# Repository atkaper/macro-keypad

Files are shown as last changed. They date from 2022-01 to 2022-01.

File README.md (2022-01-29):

# Macro Keypad

The Macro Keypad is an 8 key USB keyboard, with programmable keys, and a led in each key.
See blog post: https://www.kaper.com/electronics/macro-keypad/ for schematics, more information, and on
how to build this.

## Some images of the end result

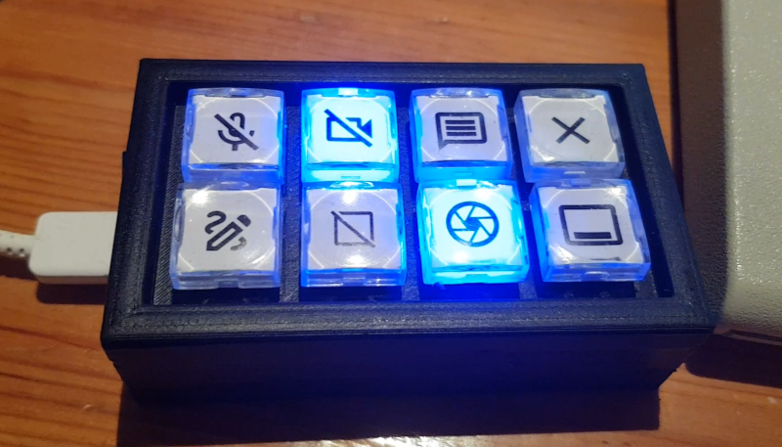
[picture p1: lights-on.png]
Lights On


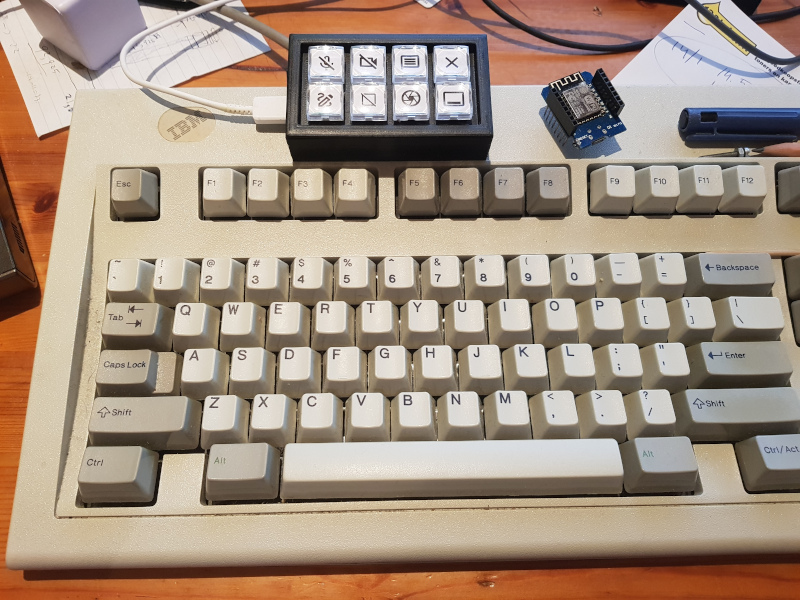
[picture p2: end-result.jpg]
End Result


## Used components

The next (2) titles are taken from the Aliexpress site, where I ordered the parts:

- Honyone TS26 Series Square With LED Momentary SPST PCB Mini Push Button Tact Switch -->  [12x 0.81 euro, when I bought them].
- PRO MICRO/MINI/TYPE-C USB 5V 16MHz Board Module For Arduino/Leonardo ATMEGA32U4-AU/MU Controller Pro-Micro Replace Pro Mini 1PCS -->  [1x 5.62 euro, when I bought it - I took the USB-C one].
- 8x 100 Ohm resistor (taken from a previously ordered set of many resistor values).
- Some spare through-hole protoboard (experiment printed circuit board).

## Files/Folders in this Git Repository

Folders:

- ```3d-files``` ; contains the blender and STL files to print the case.
- ```MacroKeyPad``` ; contains the Arduino code to run on the microcontroller.
- ```Linux-Tools``` ; contains Linux scripts I use for executing macro's and talking to the keypad lights.

Linux-Tools Files:

- ```key-macros.sh``` ; a shell script which can execute some functions I needed. These include talking to MS-Teams
  chat/video, drawing on screen, region-screenshot, and starting a terminal/shell.
- ```send-macropad-command.py``` ; python script to change led states, and change key functions/mappings.

## Compile code / program the controller

The ```MacroKeyPad.ino``` in the ```MacroKeyPad``` folder can be opened in the Arduino IDE (see https://www.arduino.cc/).
To compile the code ("sketch"), you need to add support for the Arduino Leonardo ATMEGA 32U4 Pro micro.
Use this URL as board manager setting (Files / Preferences / Additional Boards Manager URLs):
https://raw.githubusercontent.com/sparkfun/Arduino_Boards/master/IDE_Board_Manager/package_sparkfun_index.json
Via: Tools / Board / Boards Manager you can add missing boards.

In Tools menu: Choose board "SparkFun Pro Micro", CPU 16 MHZ, 5V. And the proper device to send it to.
For me that was: /dev/ttyACM0. And then hit the "upload" button.
If it does not understand some of the used includes, you might need to add some libraries using the:
Sketch / Include Library / Manage Libraries menu item.

Unfortunately, my Arduino IDE already has all stuff I need, so I do not know what you will need to add ;-)
Perhaps one day I'll try a fresh installation to write down the exact steps. For now, just use an internet
search if you get stuck.

After you did program the controller, and completed building it, you are ready to test it.
The ```send-macropad-command.py``` tool can be used to change behaviour, and change led states.
And for the rest you will need to either put the proper key you need in the keypad definition, or
use your operating systems keyboard mapping possibilities or external tools to add special actions on each
key-press.

For me this was simple. I have mapped the F13..F22 keys to the keypad, and in Linux Mint, I can simply
open up the Keyboard GUI program to assign Application Shortcuts to those keys. As shortcuts I used the
shell script ```key-macros.sh``` for the different functions. But some of these can also be done directly in the
Keyboard GUI settings.

Note: the two ```Linux-Tools``` script files should be places in a ```bin``` folder in your path. I used my
bin folder in my user's home directory for that, and added it to the PATH setting.

For more information, see the blog-post as mentioned at the top of this page.

Thijs Kaper, January 29, 2022.

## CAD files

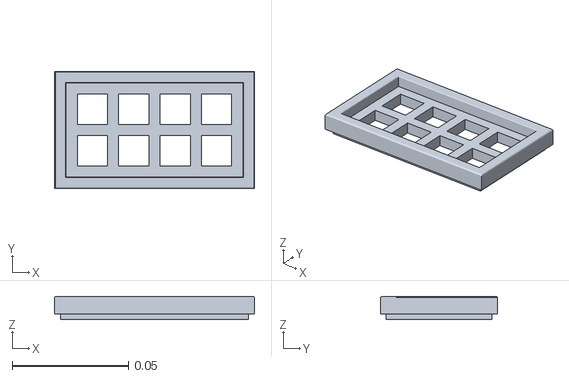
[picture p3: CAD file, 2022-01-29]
3d-files/macropad-top.stl
0.086 x 0.0504 x 0.01

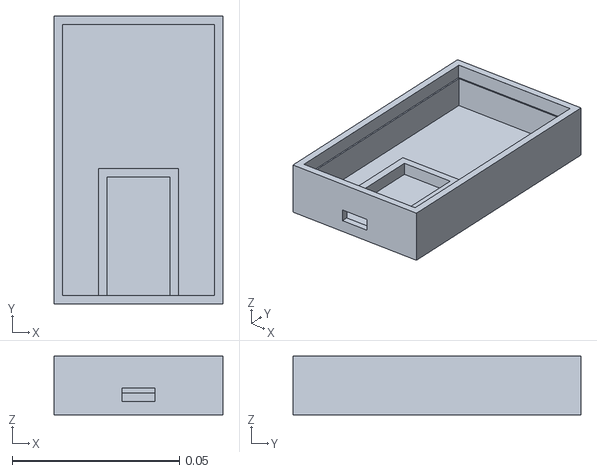
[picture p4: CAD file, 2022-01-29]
3d-files/macropad-bottom.stl
0.0504 x 0.086 x 0.0175

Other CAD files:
3d-files/macropad-bottom.blend
3d-files/macropad-top.blend

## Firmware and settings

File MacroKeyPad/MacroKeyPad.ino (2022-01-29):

#include "Keyboard.h"
#include <Keypad.h>
#include <EEPROM.h>

// KeyPad, 8 keys, with (single color) leds in them.
//
// Arduino Leonardo Compatible - ATMEGA 32U4-AU/MU - Pro micro.
// USB Device HID/Mouse/Keyboard/etc...
// Board info: https://learn.sparkfun.com/tutorials/pro-micro--fio-v3-hookup-guide/all
//
// Arduino IDE board manager url: https://raw.githubusercontent.com/sparkfun/Arduino_Boards/master/IDE_Board_Manager/package_sparkfun_index.json
// Choose board "SparkFun Pro Micro", CPU 16 MHZ, 5V.
//
// Linux/Ubuntu, show which key has been pressed: "sudo showkey -s" or "sudo showkey -k"
// Note: The keypad will also work on windows, it is just simulating an USB keyboard.
// 
// Thijs Kaper, January 29, 2022.

// Enable next line if you want double click on key 8 to toggle between keymap 1 and 2, and key 7 to show startup animation (was only for testing).
//#define DOUBLE_CLICK_TEST

// Just some random version number (can be queried via serial command interface).
const char VERSION[] PROGMEM = "MacroPad-1.0, " __DATE__ " " __TIME__;

// Key matrix size setup
const byte ROWS = 2;
const byte COLS = 4;
const byte KEYCOUNT = (ROWS * COLS);

// Key matrix pin connections:
const byte rowPins[ROWS] = { 10, 16 }; //connect to the row pinouts of the keypad.
const byte colPins[COLS] = { A1, A0, 15, 14 }; //connect to the column pinouts of the keypad.

// Led to pin mapping
const byte ledPin[KEYCOUNT] = { 2, 3, 4, 5, 6, 7, 8, 9 }; // Led nr is index (0 based), value is controller pin number.

// Assign indexes to keymap, we use the indexes as pointer into keyMap1 or keyMap2 (after subtracting 1).
// The index starts at 1, because reading the keypad will return 0 if there was none, so we can not use 0 as index.
// Normally you would just put the "real" keys in this array, but I wanted to be able to choose between 2 keymaps,
// so I did just put in index in here, to point into my two keymaps.
const char keys[ROWS][COLS] = {
  { 1, 2, 3, 4 },
  { 5, 6, 7, 8 },
};

// The data in this configuration struct can be modified at runtime via serial port, and persisted in EEPROM for use on fresh boot.
struct ConfigData {
  // keyMap1 defintion, the one used by default after power on. You can fill in special keynames
  // as seen in arduino-*/libraries/Keyboard/src/Keyboard.h, or just use ascii code chars, e.g. '0' or 'a'.
  // My defintion, F13-F22. Skipping two f-keys, as these do not seem to work on linux mint? (F19/F20 moved to F21/F22).
  char keyMap1[KEYCOUNT] = { KEY_F13, KEY_F14, KEY_F15, KEY_F16, KEY_F17, KEY_F18, KEY_F21, KEY_F22 };
  
  // Alternate keymap, just for testing the keys, sending normal digits. Same comment as for keyMap1.
  char keyMap2[KEYCOUNT] = { '1', '2', '3', '4', '5', '6', '7', '8' };
  
  // Configuration of led action when key is pressed. Initial start, set to auto toggle (t).
  // Options: t = toggle, e = enable(on), d = disable(off), f = flash 150 ms.
  char ledConfig1[KEYCOUNT] = { 't', 't', 't', 't', 't', 't', 't', 't' };
  char ledConfig2[KEYCOUNT] = { 't', 't', 't', 't', 't', 't', 't', 't' };
} config;

// Startup animation, led numbers to light, 1 based to easily match up keys (not zero based).
// Animation lights up 2 leds at a time.
const byte ledAnimation[][2] = {
  { 1, 8 },
  { 2, 7 },
  { 3, 6 },
  { 4, 5 },
  { 8, 1 },
  { 7, 2 },
  { 6, 3 },
  { 5, 4 },
  { 1, 8 },
};

// Toggle flag to change keymap. Default starts using keyMap1. You can toggle to keyMap2 using double click on key 8 (if DOUBLE_CLICK_TEST defined), or by sending a command from PC via serial.
// Note: the second keymap was not meant for any serious use (just testing), as double clicking key 8 will also send the configured key function on its first press.
boolean useAlternateKeyMap=false;

// Initialze keypad functions.
Keypad keypad = Keypad( makeKeymap(keys), rowPins, colPins, ROWS, COLS );

// Led state memory.
byte ledState[KEYCOUNT]; // on = 1 / off = 0

// Helper function to determine length of array.
#define membersof(x) (sizeof(x) / sizeof(x[0]))

// memorize when last keypress occurred.
unsigned long startTime = millis();

// memorize last key press.
char lastKey = '-';

// Serial data buffer.
char readBuffer[80];
char *readBufferPtr;

// Reset serial data buffer.
void clearReadBuffer() {
  readBuffer[0] = 0;
  readBufferPtr = readBuffer;
}

// Initialize all.
void setup() {
  Serial.begin(115200);

  // Load config data from EEPROM.
  handleLoad();
  
  // Initialize readBuffer to blank/empty-string.
  clearReadBuffer();
  
  // Set LED pins as output, and turn off.
  for (int i=0;i<KEYCOUNT;i++) {
    pinMode(ledPin[i], OUTPUT);
    setLed(i, 0);
  }

  // Start USB keyboard.
  Keyboard.begin();

  // Show startup lightshow.
  startupLedAnimation();
}

// Animation code
void startupLedAnimation() {
  // Backup current led state, in case we re-start animation during use.
  static byte currentLedState[ROWS*COLS];
  for(int i=0;i<KEYCOUNT;i++) {
    currentLedState[i] = ledState[i];
  }

  // Run through animation "frames".
  for (int i=0; i< membersof(ledAnimation); i++) {
    // Turn leds on
    setLed(ledAnimation[i][0]-1, 1);
    setLed(ledAnimation[i][1]-1, 1);
    if (i>0) {
      // Turn previous leds off
      setLed(ledAnimation[i-1][0]-1, 0);
      setLed(ledAnimation[i-1][1]-1, 0);
    }
    delay(250);
  }
  // Turn last ones off.
  setLed(ledAnimation[membersof(ledAnimation)-1][0]-1, 0);
  setLed(ledAnimation[membersof(ledAnimation)-1][1]-1, 0);

  // Restore led state, in case we ran animation during use.
  for(int i=0;i<KEYCOUNT;i++) {
    setLed(i, currentLedState[i]);
  }
}

// Set (zero based index) led on or off; 1 = on, 0 = off.
void setLed(int nr, int onOff) {
  if (nr<0 || nr>=KEYCOUNT || onOff<0 || onOff>1) return;
  ledState[nr] = onOff;
  digitalWrite(ledPin[nr], (onOff==1)?LOW:HIGH);
}

// Toggle led (zero based index).
void toggleLed(int nr) {
  if (nr<0 || nr>=KEYCOUNT) return;
  if (ledState[nr] == 0) {
    setLed(nr, 1);
  } else {
    setLed(nr, 0);
  }
}

// Change led state, on key-press, according to what has been confgiured for it.
void executeLedConfig(int nr) {
  if (nr<0 || nr>=KEYCOUNT) return;
  char setting;
  if (useAlternateKeyMap) {
    setting = config.ledConfig2[nr];
  } else {
    setting = config.ledConfig1[nr];
  }
  // Options: t = toggle, e = enable(on), d = disable(off), f = flash 150 ms.
  if (setting == 't') {
    toggleLed(nr);
  }
  if (setting == 'e') {
    setLed(nr, 1);
  }
  if (setting == 'd') {
    setLed(nr, 0);
  }
  if (setting == 'f') {
    setLed(nr, 1);
    delay(150);
    setLed(nr, 0);
    delay(150);
  }
}

// Read number from the serial data buffer.
int parseNumber(int minValue, int maxValue) {
  // Parse next word into a (zero or positive) number.
  char *nextword = strtok(NULL, " ");
  if (nextword == NULL) {
    Serial.print("Error, missing number\n");
    return -1;
  }
  int nr = atoi(nextword);
  if (nr<minValue || nr>maxValue) {
    Serial.print("Error, expected number from ");
    Serial.print(minValue);
    Serial.print(" to ");
    Serial.println(maxValue);
    return -1;
  }
  return nr;
}

// Create function "template".
typedef int (*HandlerFunction)();

// Create struct with function, name, description.
struct HandlerEntry {
  char *shortcode;
  char *command;
  char *help;
  HandlerFunction handler;
};

// Stored all long text messages in PROGMEM, this does require them to be copied back using strncpy_P to use them.
const char MSG_HELP_START[]   PROGMEM = "Valid commands:\n";
const char MSG_HELP[]         PROGMEM = "help                    : [or ?] show this help";
const char MSG_VERSION[]      PROGMEM = "version                 : [or v] show the macropad version";
const char MSG_GETLED[]       PROGMEM = "getled <NR>             : [or g] get led <NR> state (return 0 for off or 1 for on)";
const char MSG_TOGGLE[]       PROGMEM = "toggle <NR>             : [or t] toggle led <NR> state (<NR> is 1..8)";
const char MSG_ON[]           PROGMEM = "on <NR>                 : [or e] turn led <NR> on/enable (<NR> is 1..8)";
const char MSG_OFF[]          PROGMEM = "off <NR>                : [or d] turn led <NR> off/disable (<NR> is 1..8)";
const char MSG_FLASH[]        PROGMEM = "flash <NR> <MS>         : [or f] turn led <NR> on, sleep <MS> milliseconds, turn off, and sleep same time again (<NR> is 1..8, <MS> is 10..500)";
const char MSG_ANIMATION[]    PROGMEM = "animation               : [or a] run startup led animation";
const char MSG_USEMAP[]       PROGMEM = "usemap <NR>             : [or u] enable keymap <NR> (<NR> is 1 or 2)";
const char MSG_CONFIGTOGGLE[] PROGMEM = "configtoggle <NR> <SET> : [or c] configure key led toggle for key <NR> (1..8), <SET> is one of [t,e,d,f] where flash will be 150ms";
const char MSG_SHOWSETTINGS[] PROGMEM = "showsettings            : [or s] show settings";
const char MSG_SETKEYCODE[]   PROGMEM = "setkeycode <NR> <CODE>  : [or k] set key code of key <NR> (1..8) to <CODE> 0..255";
const char MSG_SETKEYCHAR[]   PROGMEM = "setkeychar <NR> <CHAR>  : [or h] set key character of key <NR> (1..8) to <CHAR> (a single char)";
const char MSG_PERSIST[]      PROGMEM = "persist                 : [or p] write config to EEPROM (use if you change keys or configtoggles)";
const char MSG_LOAD[]         PROGMEM = "load                    : [or l] load config from EEPROM (automatically done on each startup)";
const char MSG_HELP_END[]     PROGMEM = "\nYou can put multiple commands in one line - up to 79 characters (space separated), example: 'on 1 toggle 7 off 3'\n";

// List of all possible commands.
const HandlerEntry handlers[] = {
  { "?", "help",          MSG_HELP,         &handleHelp },
  { "v", "version",       MSG_VERSION,      &handleVersion },
  { "g", "getled",        MSG_GETLED,       &handleGetLed },
  { "t", "toggle",        MSG_TOGGLE,       &handleToggle },
  { "e", "on",            MSG_ON,           &handleOn },
  { "d", "off",           MSG_OFF,          &handleOff },
  { "f", "flash",         MSG_FLASH,        &handleFlash },
  { "a", "animation",     MSG_ANIMATION,    &handleAnimation },
  { "u", "usemap",        MSG_USEMAP,       &handleActivateKeyMap },
  { "c", "configtoggle",  MSG_CONFIGTOGGLE, &handleConfigToggle },
  { "s", "showsettings",  MSG_SHOWSETTINGS, &handleShowSettings },
  { "k", "setkeycode",    MSG_SETKEYCODE,   &handleSetKeyCode },
  { "h", "setkeychar",    MSG_SETKEYCHAR,   &handleSetKeyChar },
  { "p", "persist",       MSG_PERSIST,      &handlePersist },
  { "l", "load",          MSG_LOAD,         &handleLoad },
};

// Print char* from PROGMEM (copy to normal memory, and then print)
void println_P(char *data_P) {
  // Would be nice if we could determine length of string in progmem, and define buffer of that size.
  // Shortcut for now, just set 200 as max, and fix when needed.
  char tmp[200];
  strncpy_P(tmp, data_P, 199);
  Serial.println(tmp);
}

// Help command, show list.
int handleHelp() {
  println_P(MSG_HELP_START);
  for(int i=0; i<membersof(handlers);i++) {
    println_P(handlers[i].help);
  }
  println_P(MSG_HELP_END);
  return 0;
}

// Show version number.
int handleVersion() {
  println_P(VERSION);
  return 0;
}

// Get led state.
int handleGetLed() {
  int nr = parseNumber(1, KEYCOUNT);
  if (nr == -1) return 1;
  Serial.println(ledState[nr-1]);
  return 0;
}

// Toggle led.
int handleToggle() {
  int nr = parseNumber(1, KEYCOUNT);
  if (nr == -1) return 1;
  toggleLed(nr-1);
  return 0;
}

// Turn on led.
int handleOn() {
  int nr = parseNumber(1, KEYCOUNT);
  if (nr == -1) return 1;
  setLed(nr-1, 1);
  return 0;
}

// Turn off led.
int handleOff() {
  int nr = parseNumber(1, KEYCOUNT);
  if (nr == -1) return 1;
  setLed(nr-1, 0);
  return 0;
}

// Flash led.
int handleFlash() {
  int nr = parseNumber(1, KEYCOUNT);
  if (nr == -1) return 1;
  int ms = parseNumber(10, 500);
  if (ms == -1) return 1;
  setLed(nr-1, 1);
  delay(ms);
  setLed(nr-1, 0);
  delay(ms);
  return 0;
}

// Execute led animation.
int handleAnimation() {
  startupLedAnimation();
  return 0;
}

// Switch to keymap.
int handleActivateKeyMap() {
  int nr = parseNumber(1, 2);
  if (nr == -1) return 1;
  useAlternateKeyMap = (nr == 2);
  return 0;
}

// Configure led toggle behavior.
int handleConfigToggle() {
  int nr = parseNumber(1, KEYCOUNT);
  if (nr == -1) return 1;
  char *setting = strtok(NULL, " ");
  if (setting == NULL || strstr("tedf", setting) == NULL || strlen(setting) != 1) {
    Serial.println("Expected setting flag, one of [t,e,d,f].");
    return 1;
  }
  if (useAlternateKeyMap) {
    config.ledConfig2[nr-1] = setting[0];
  } else {
    config.ledConfig1[nr-1] = setting[0];
  }
  return 0;
}

// Show configuration (for active keymap).
int handleShowSettings() {
  Serial.println(useAlternateKeyMap?"map 2 active":"map 1 active");
  for(int i=0; i<KEYCOUNT; i++) {
    static char buffer[60];
    if(useAlternateKeyMap) {
      sprintf(buffer, "key %d, led: %s, ledconfig: %c, keycode: %d", i+1, ledState[i]?"on":"off", config.ledConfig2[i], (uint8_t) config.keyMap2[i]);
    } else {
      sprintf(buffer, "key %d, led: %s, ledconfig: %c, keycode: %d", i+1, ledState[i]?"on":"off", config.ledConfig1[i], (uint8_t) config.keyMap1[i]);
    }
    Serial.println(buffer);
  }
  return 0;
}

// Change the function of a macro key, by code, e.g, 65 = A, 240 = F13.
int handleSetKeyCode() {
  int nr = parseNumber(1, KEYCOUNT);
  if (nr == -1) return 1;
  int code = parseNumber(0, 255);
  if (code == -1) return 1;
  if(useAlternateKeyMap) {
    config.keyMap2[nr-1] = (char) (code & 255);
  } else {
    config.keyMap1[nr-1] = (char) (code & 255);
  }
  return 0;
}

// Change the function of a macro key, by char.
int handleSetKeyChar() {
  int nr = parseNumber(1, KEYCOUNT);
  if (nr == -1) return 1;
  char *value = strtok(NULL, " ");
  if (value == NULL || strlen(value) != 1) {
    Serial.println("Expected single character.");
    return 1;
  }
  if(useAlternateKeyMap) {
    config.keyMap2[nr-1] = value[0];
  } else {
    config.keyMap1[nr-1] = value[0];
  }
  return 0;
}

// Store config settings in EEPROM.
int handlePersist() {
  int eeAddress = 0;
  int version = 2306;
  EEPROM.put(eeAddress, version);
  eeAddress += sizeof(version);
  EEPROM.put(eeAddress, config);
  Serial.println("Config persisted.");
  return 0;
}

// Load config settings from EEPROM, also called on startup.
int handleLoad() {
  // Load config from EEPROM if there is a valid checksum there.
  int eeAddress = 0;
  int version;
  EEPROM.get(eeAddress, version);
  if (version == 2306) {
    eeAddress += sizeof(version);
    EEPROM.get(sizeof(version), config);
    Serial.println("Config loaded.");
  }
  return 0;
}

// Find commands in serial input, and execute them.
void executeSerialCommands() {
  char *word;
  word = strtok(readBuffer, " ");
  while (word != NULL) {
    boolean ok = false;

    for(int i=0; i<membersof(handlers);i++) {
      if(strcmp(handlers[i].command, word) == 0 || strcmp(handlers[i].shortcode, word) == 0) {
        if(handlers[i].handler()) return;
        ok = true;
        break;
      }
    }
    
    if (!ok) {
      Serial.print("Unknown Command Error\n");
      // Ignore the rest of the line.
      return;
    }

    // Check if there is a next command.
    word = strtok(NULL, " ");
  }
}

// Check and store serial data.
void handleSerialReceive() {
  while(Serial.available()>0) {
    char ser = Serial.read();
    // Collect received data in readBuffer, until someone sends "enter" (cr and or lf).
    if (strlen(readBuffer) < (sizeof(readBuffer)-1) && ser != 13 && ser !=10) {
      // Add new char to buffer.
      *(readBufferPtr++) = ser;
      *readBufferPtr = 0;
    }
    // "enter" (cr and or lf) pressed? handle data (if any).
    if ((ser == 13 || ser == 10) && strlen(readBuffer) > 0) {
      executeSerialCommands();
      clearReadBuffer();
    }
  }
}

// main loop
void loop() {
  handleSerialReceive();
  
  // key returns our 1 based index 1..8, or 0 if no key was pressed.
  char key = keypad.getKey();
 
  if (key){
    char keyIndex = key - 1;

#ifdef DOUBLE_CLICK_TEST
    // Check if key'8' was pressed twice quickly, if so, toggle keymap.
    if (key == 8 && lastKey == 8 && ((millis()-startTime) < 600)) {
      // toggle keymap between keyMap1 and keyMap2.
      useAlternateKeyMap = !useAlternateKeyMap;
      toggleLed(useAlternateKeyMap?0:4); delay(250); toggleLed(useAlternateKeyMap?0:4); // flash led 1 or 5 to confirm toggle (1 = numeric keys, 5 = function keys)
      delay(250);
      toggleLed(useAlternateKeyMap?0:4); delay(250); toggleLed(useAlternateKeyMap?0:4); // flash led 1 or 5 to confirm toggle (1 = numeric keys, 5 = function keys)
      startTime = millis();
      delay(20);
      return;
    }

    // Check if key'7' was pressed twice quickly, if so show startup led animation.
    if (key == 7 && lastKey == 7 && ((millis()-startTime) < 600)) {
      startupLedAnimation();
      startTime = millis();
      delay(20);
      return;
    }
#endif

    // Send key press to PC via USB
    Keyboard.write(useAlternateKeyMap ? config.keyMap2[keyIndex] : config.keyMap1[keyIndex]);
    lastKey = key;
    executeLedConfig(keyIndex);
    startTime = millis();
  }
  delay(20);
}

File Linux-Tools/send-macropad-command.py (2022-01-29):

#!/usr/bin/python3

"""
send-macropad-command.py

This tool can be used to interact with the macro key pad from within batch scripts,
or from the shell/bash command line.

Type:
- "send-macropad-command.py -h" for help about this tool.
- "send-macropad-command.py help" for help about the macro pad commands.

This last help, needs a functioning macro pad connected, and proper detection of
the com port / device to use. If auto detection does not work, execute:

"send-macropad-command.py -v -l" to debug it.

Fixing auto detect can be done either by using the -d option, or by finding
some unique words in the "-l" data-set, and passing these in via "-a".

Thijs Kaper, January 29, 2022.
"""

# Silence some pylint warnings (non-standard names or globals, too general exception catching)
#pylint:disable=C0103,W0703,W0603

import argparse
import re
import textwrap
import sys
import threading
import serial
import serial.tools.list_ports

# Define command line argument parser
parser = argparse.ArgumentParser(
    formatter_class=argparse.RawDescriptionHelpFormatter,
    description='Send command to macro keypad',
    epilog=textwrap.dedent('''\
        Note: if you use the 'f' or 'flash' command, you need to increase the timeout if you also
        need a response to be read. Count each flash time double (one for on, one for off time).

        Examples:
        %(prog)s -v -l                       # debug port autodetection
        %(prog)s -a "9206 hidpc" -l -v       # change auto detect keywords to find proper macro pad device
        %(prog)s help                        # get command help
        %(prog)s -t 0.3 help                 # get command help, use increased timeout on slow computer
        %(prog)s -t 0.5 t 2 f 1 200 e 2 g 1  # toggle 2, flash 1 for 200ms, and turn on 2 after that, read 1
        %(prog)s -d /dev/ttyACM0 t 1         # toggle led 1, use device /dev/ttyACM0 instead of autodetecting the device
        _
        ''')
    )
parser.add_argument(dest='commands', metavar='command', nargs='*')
parser.add_argument('-i', '--interactive', dest='interactive', action='store_true',
                    help='interactive mode (end with "exit" or ctrl-d)')
parser.add_argument('-v', '--verbose', dest='verbose', action='store_true',
                    help='verbose / debug mode')
parser.add_argument('-q', '--quiet', dest='quiet', action='store_true', help='quiet / silent mode')
parser.add_argument('-l', '--list', dest='list', action='store_true', help='list serial ports')
parser.add_argument('-t', '--timeout', metavar='timeout', type=float, dest='timeout', default=0.1,
                    help='time to wait for macro keypad to send a response to the command'
                    ' (default %(default)s, if partial or no response, change to 0.2 or higher)')
parser.add_argument('-b', '--baud-rate', metavar='bps', type=int, dest='baud_rate', default=115200,
                    help='baud rate, not interesting for atmega-32u4, but might be for others'
                    ' (default %(default)s)')
group = parser.add_mutually_exclusive_group()
group.add_argument('-d', '--device', metavar='device', dest='device',
                   help='serial device to use (example /dev/ttyACM0)')
group.add_argument('-a', '--autodetect', metavar='matchwords', dest='autodetect',
                   default='1B4F:9206 SparkFun',
                   help='auto detect serial port hwid/description words (default: %(default)s)')
args = parser.parse_args()

def debug(data):
    """Debug / verbose conditional print function (enable with -v)"""
    if args.verbose:
        print("# " + data)

# Autodetect the port to use. Will be overwritten later, if someone specified the -d flag.
autodetectregex = ".*" + (args.autodetect.lower()).replace(" ", ".*") + ".*"
comportlist = serial.tools.list_ports.comports()
device = None
debug("Autodetect search regex: " + autodetectregex)
for element in comportlist:
    finder = (str(element.hwid) + " " + str(element.description)).lower()
    debug("For device " + element.device + "; Autodetect string to match against: " + finder)
    if re.match(autodetectregex, finder):
        debug("Match: autodetected device: " + element.device)
        if device and not args.device:
            print("WARNING: multiple matches on autodetect. Last match will be used."
                  "Use -v and -l options to investigate, and change -a or -d value to fix this!")
            print("Previous match: " + device + ", current match: " + element.device)
        device = element.device

# If the -l option was used, show available serial ports,
# and show which one would be chosen from the autodetect keywords.
if args.list:
    print("The following serial ports are found:\n")
    for element in comportlist:
        print("device:" + element.device + "\n    description:" + str(element.description) +
              "\n    hwid:" + str(element.hwid) + "\n")
    print("Based on the autodetect setting keywords, we would choose: " + str(device))
    sys.exit(0)

# Override device when -d defined.
if args.device:
    debug("Overriding autodetected device " + str(device) + " with " + args.device)
    device = args.device

debug("Device to use: " + device + ", " + str(args.baud_rate) + " baud")

# Check if the user specified either any commands to send or to use interactive mode.
if (not args.commands) != args.interactive:
    print("Either specify a command as argument, or use -i for interactve mode.\n")
    parser.print_help()
    sys.exit(1)

# Open the serial port.
try:
    ser = serial.Serial(device, args.baud_rate, timeout=args.timeout)
except Exception as msg:
    print("Error opening serial port " + device + ", error: " + str(msg))
    sys.exit(1)

# Flag for use in interactive mode to indicate (not) end of processing.
keep_reading = True

# response read function
def read_response():
    """Try to read response, catch any excpetions."""
    global ser, keep_reading
    try:
        response = ser.read(size=2048).decode('utf-8').strip()
    except Exception as msg:
        print("Error reading response: " + str(msg))
        keep_reading = False
        return None
    return response

# reader thread function
def response_reader_thread():
    """Routine for background thread to keep reading and printing data as read from serial port."""
    global keep_reading
    debug("Start background thread for reading responses")
    while keep_reading:
        response = read_response()
        if response:
            print(response)
    debug("End background thread for reading responses")
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
